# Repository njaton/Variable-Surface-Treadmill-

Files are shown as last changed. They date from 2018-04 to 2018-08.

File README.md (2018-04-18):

# Variable-Surface-Treadmill-

Code Written by Nick Jaton

Project Co-authors Travis Vanderheyden, Dr. Kota Takahashi

This program was created as a proof of concept for the Variable Surface Treadmill Project funded by a NASA Nebraska Space Grant.This program will use three buttons to operate the motors used in the proof of concept. One button is a value generator, one lifts the cell and one resets the cell. The cell movement was operated with a small motor. A TB6612 was used to control the motors.

The Power circuit on the PCB has not yet been tested so please use with caution. The PCB and Schematic are both Eagle files.

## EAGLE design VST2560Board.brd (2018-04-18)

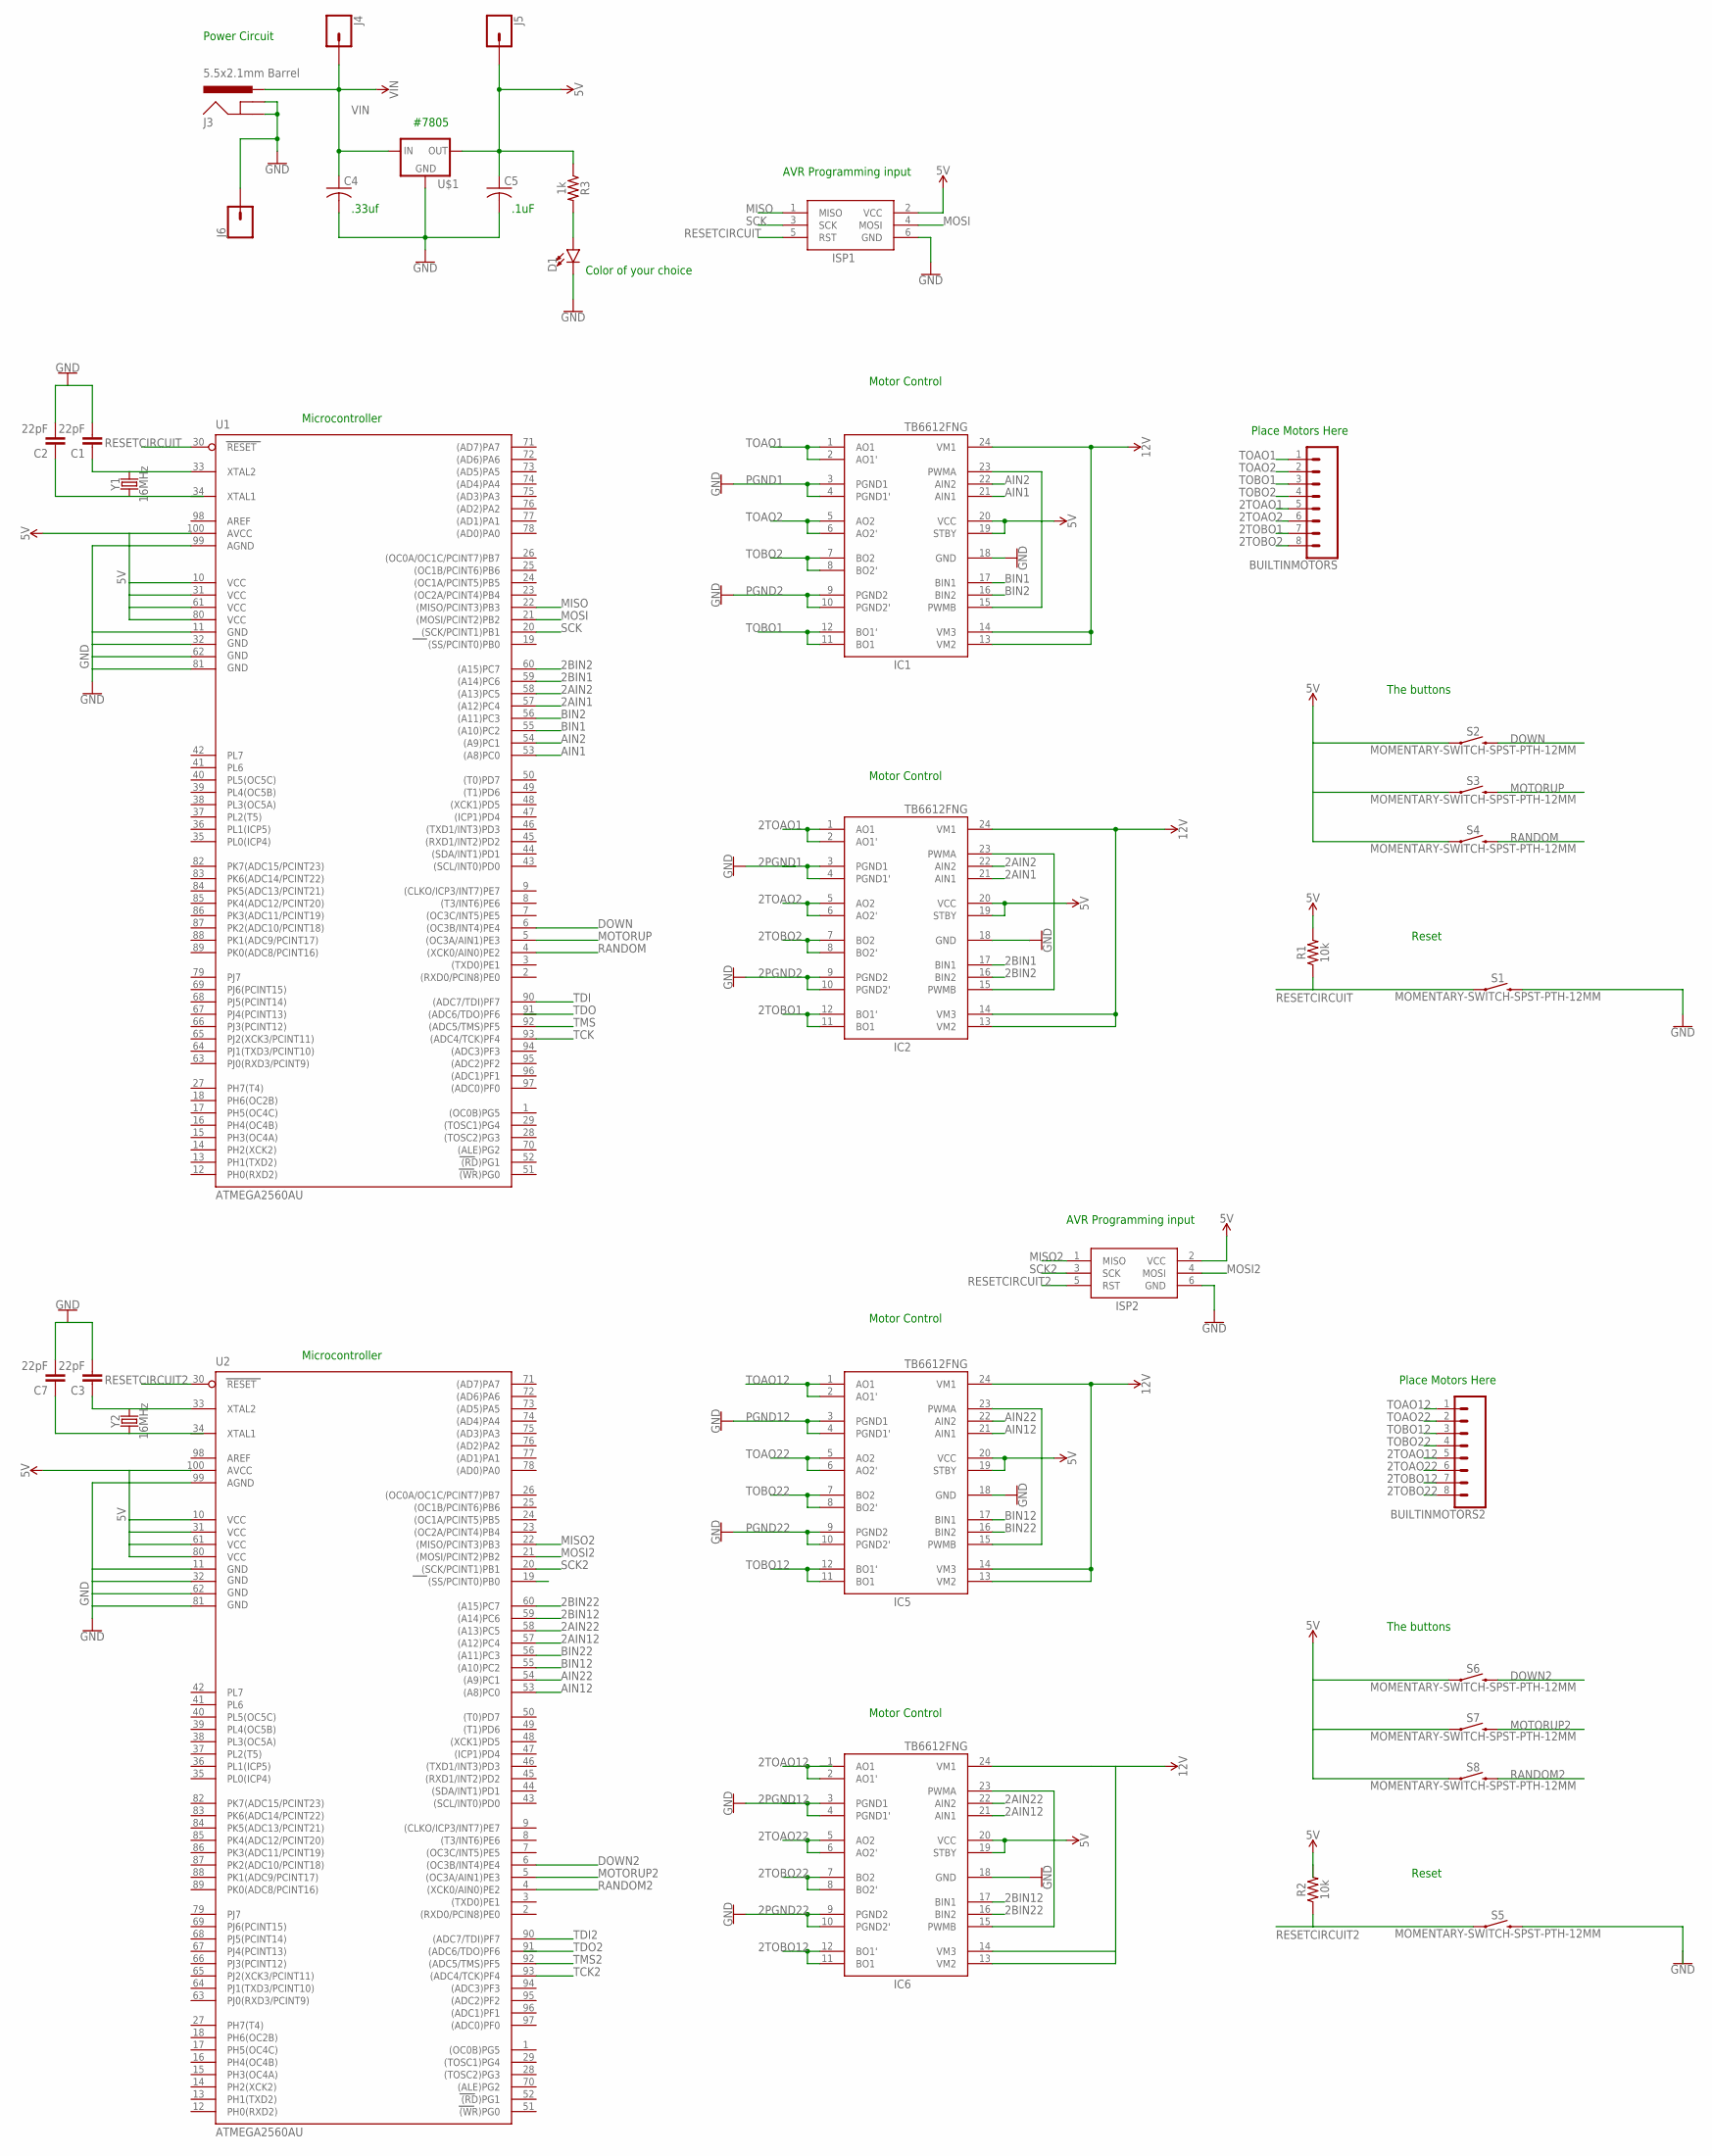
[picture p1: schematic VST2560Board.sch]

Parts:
BUILTINMOTORS, BUILTINMOTORS2: CONN_08"; 1X08
C1, C2, C3, C7: 22pF; 0603
C4, C5: C-USC0603; C0603
D1: LED3MM; LED_3MM
IC1, IC2, IC5, IC6: TB6612FNG; SSOP24
ISP1, ISP2: AVRISP-BOX
J3: 5.5x2.1mm Barrel; POWER_JACK_SMD
J4, J5, J6: CONN_01; 1X01
R1, R2: 10k; AXIAL-0.3
R3: 1k; 0603
S1, S2, S3, S4, S5, S6, S7, S8: MOMENTARY-SWITCH-SPST-PTH-12MM; TACTILE_SWITCH_PTH_12MM
U1, U2: ATMEGA2560AU; TQFP100
U$1: V_REG_LD1117VXX; 78XXL
Y1, Y2: 16MHz; HC49US

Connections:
2AIN1: IC2.21 (AIN1), U1.57 ((A12)PC4)
2AIN2: IC2.22 (AIN2), U1.58 ((A13)PC5)
2AIN12: IC6.21 (AIN1), U2.57 ((A12)PC4)
2AIN22: IC6.22 (AIN2), U2.58 ((A13)PC5)
2BIN1: IC2.17 (BIN1), U1.59 ((A14)PC6)
2BIN2: IC2.16 (BIN2), U1.60 ((A15)PC7)
2BIN12: IC6.17 (BIN1), U2.59 ((A14)PC6)
2BIN22: IC6.16 (BIN2), U2.60 ((A15)PC7)
2PGND1: IC2.3 (PGND1), IC2.4 (PGND1')
2PGND2: IC2.9 (PGND2), IC2.10 (PGND2')
2PGND12: IC6.3 (PGND1), IC6.4 (PGND1')
2PGND22: IC6.9 (PGND2), IC6.10 (PGND2')
2TOAO1: BUILTINMOTORS.5, IC2.1 (AO1), IC2.2 (AO1')
2TOAO2: BUILTINMOTORS.6, IC2.5 (AO2), IC2.6 (AO2')
2TOAO12: BUILTINMOTORS2.5, IC6.1 (AO1), IC6.2 (AO1')
2TOAO22: BUILTINMOTORS2.6, IC6.5 (AO2), IC6.6 (AO2')
2TOBO1: BUILTINMOTORS.7, IC2.11 (BO1), IC2.12 (BO1')
2TOBO2: BUILTINMOTORS.8, IC2.7 (BO2), IC2.8 (BO2')
2TOBO12: BUILTINMOTORS2.7, IC6.11 (BO1), IC6.12 (BO1')
2TOBO22: BUILTINMOTORS2.8, IC6.7 (BO2), IC6.8 (BO2')
5V: C5.1, IC1.15 (PWMB), IC1.19 (STBY), IC1.20 (VCC), IC1.23 (PWMA), IC2.15 (PWMB), IC2.19 (STBY), IC2.20 (VCC), IC2.23 (PWMA), IC5.15 (PWMB), IC5.19 (STBY), IC5.20 (VCC), IC5.23 (PWMA), IC6.15 (PWMB), IC6.19 (STBY), IC6.20 (VCC), IC6.23 (PWMA), ISP1.2 (VCC), ISP2.2 (VCC), J5.1, R1.P$2 (2), R2.P$2 (2), R3.1, S2.1, S3.1, S4.1, S6.1, S7.1, S8.1, U1.10 (VCC), U1.31 (VCC1), U1.61 (VCC2), U1.80 (VCC3), U1.100 (AVCC), U2.10 (VCC), U2.31 (VCC1), U2.61 (VCC2), U2.80 (VCC3), U2.100 (AVCC), U$1.GND (OUT)
12V: IC1.13 (VM2), IC1.14 (VM3), IC1.24 (VM1), IC2.13 (VM2), IC2.14 (VM3), IC2.24 (VM1), IC5.13 (VM2), IC5.14 (VM3), IC5.24 (VM1), IC6.13 (VM2), IC6.24 (VM1)
AIN1: IC1.21 (AIN1), U1.53 ((A8)PC0)
AIN2: IC1.22 (AIN2), U1.54 ((A9)PC1)
AIN12: IC5.21 (AIN1), U2.53 ((A8)PC0)
AIN22: IC5.22 (AIN2), U2.54 ((A9)PC1)
BIN1: IC1.17 (BIN1), U1.55 ((A10)PC2)
BIN2: IC1.16 (BIN2), U1.56 ((A11)PC3)
BIN12: IC5.17 (BIN1), U2.55 ((A10)PC2)
BIN22: IC5.16 (BIN2), U2.56 ((A11)PC3)
DOWN: S2.3 (2), U1.6 ((OC3B/INT4)PE4)
DOWN2: S6.3 (2), U2.6 ((OC3B/INT4)PE4)
GND: C1.2, C2.2, C3.2, C4.2, C5.2, C7.2, D1.K (C), IC1.18 (GND), IC2.18 (GND), IC5.18 (GND), IC6.18 (GND), ISP1.6 (GND), ISP2.6 (GND), J3.GND (GNDBREAK), J3.P$4 (GND), J6.1, S1.3 (2), S5.3 (2), U1.11 (GND), U1.32 (GND1), U1.62 (GND2), U1.81 (GND3), U1.99 (AGND), U2.11 (GND), U2.32 (GND1), U2.62 (GND2), U2.81 (GND3), U2.99 (AGND), U$1.IN (GND)
MISO: ISP1.1 (MISO), U1.22 ((MISO/PCINT3)PB3)
MISO2: ISP2.1 (MISO), U2.22 ((MISO/PCINT3)PB3)
MOSI: ISP1.4 (MOSI), U1.21 ((MOSI/PCINT2)PB2)
MOSI2: ISP2.4 (MOSI), U2.21 ((MOSI/PCINT2)PB2)
MOTORUP: S3.3 (2), U1.5 ((OC3A/AIN1)PE3)
MOTORUP2: S7.3 (2), U2.5 ((OC3A/AIN1)PE3)
unnamed: D1.A, R3.2
unnamed: C2.1, U1.34 (XTAL1), Y1.1
unnamed: C1.1, U1.33 (XTAL2), Y1.2
unnamed: C3.1, U2.33 (XTAL2), Y2.2
unnamed: C7.1, U2.34 (XTAL1), Y2.1
PGND1: IC1.3 (PGND1), IC1.4 (PGND1')
PGND2: IC1.9 (PGND2), IC1.10 (PGND2')
PGND12: IC5.3 (PGND1), IC5.4 (PGND1')
PGND22: IC5.9 (PGND2), IC5.10 (PGND2')
RANDOM: S4.3 (2), U1.4 ((XCK0/AIN0)PE2)
RANDOM2: S8.3 (2), U2.4 ((XCK0/AIN0)PE2)
RESETCIRCUIT: ISP1.5 (RST), R1.P$1 (1), S1.1, U1.30 (RESET)
RESETCIRCUIT2: ISP2.5 (RST), R2.P$1 (1), S5.1, U2.30 (RESET)
SCK: ISP1.3 (SCK), U1.20 ((SCK/PCINT1)PB1)
SCK2: ISP2.3 (SCK), U2.20 ((SCK/PCINT1)PB1)
TCK: U1.93 ((ADC4/TCK)PF4)
TCK2: U2.93 ((ADC4/TCK)PF4)
TDI: U1.90 ((ADC7/TDI)PF7)
TDI2: U2.90 ((ADC7/TDI)PF7)
TMS: U1.92 ((ADC5/TMS)PF5)
TMS2: U2.92 ((ADC5/TMS)PF5)
TOAO1: BUILTINMOTORS.1, IC1.1 (AO1), IC1.2 (AO1')
TOAO2: BUILTINMOTORS.2, IC1.5 (AO2), IC1.6 (AO2')
TOAO12: BUILTINMOTORS2.1, IC5.1 (AO1), IC5.2 (AO1')
TOAO22: BUILTINMOTORS2.2, IC5.5 (AO2), IC5.6 (AO2')
TOBO1: BUILTINMOTORS.3, IC1.11 (BO1), IC1.12 (BO1')
TOBO2: BUILTINMOTORS.4, IC1.7 (BO2), IC1.8 (BO2')
TOBO12: BUILTINMOTORS2.3, IC5.11 (BO1), IC5.12 (BO1')
TOBO22: BUILTINMOTORS2.4, IC5.7 (BO2), IC5.8 (BO2')
VIN: C4.1, J3.VIN0 (PWR), J4.1, U$1.OUT (IN)

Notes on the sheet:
Power Circuit
Microcontroller
Motor Control
The buttons
Reset
AVR Programming input
Place Motors Here
#7805
.1uF
.33uf
Color of your choice

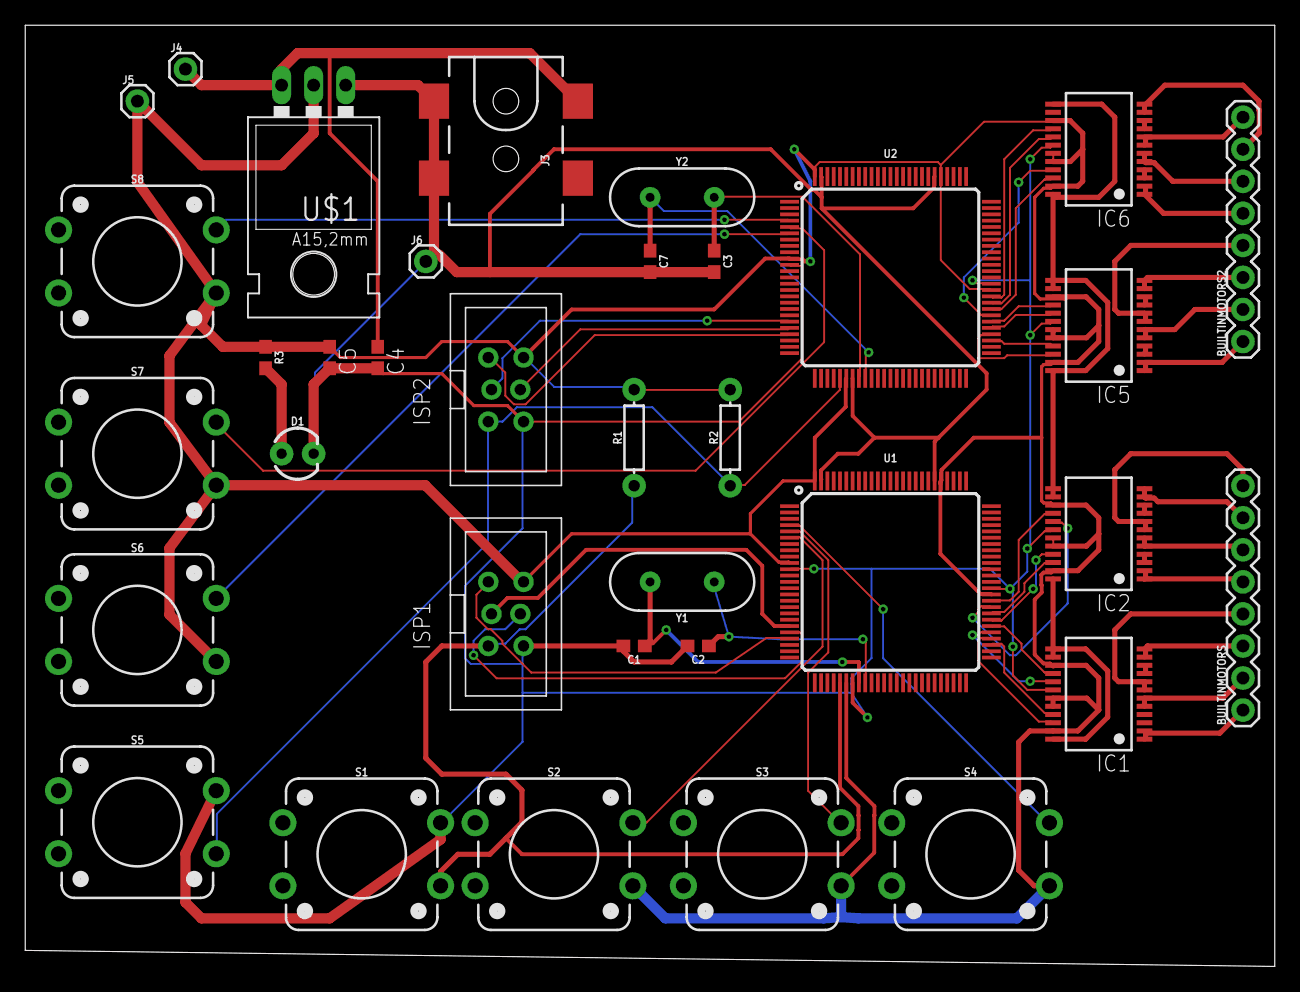
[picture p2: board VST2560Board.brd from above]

Board: 2 copper layers, 99.0 x 74.6 mm, 35 parts (0 on the bottom side), 63 nets.

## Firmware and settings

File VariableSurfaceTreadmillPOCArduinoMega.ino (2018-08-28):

//This program is used to control various motors using the TB6612 motor driver and a atmega 2560. 
//Written by: Nick Jaton
//NASA Nebraska Space Grant
// Property of : University of Nebraska's Biomechanics Research Building

#include <SparkFun_TB6612.h>

//State what pins are used for the TB6612
int MyAIN1[] = {32,40};
int MyAIN2[] = {34,42};
int MyBIN1[] = {30,38};
int MyBIN2[] = {28,36};

int PWMA = 13;
int PWMB = 12;
int PWMC = 11;
int STBY = 10;

const int offsetA = 1;
const int offsetB = -1;
const int offsetC = 1;

int AIN1 = MyAIN1[0];
int AIN2 = MyAIN2[0];

int BIN1 = MyBIN1[0];
int BIN2 = MyBIN2[0];

int AIN3 = MyAIN1[1];
int AIN4 = MyAIN2[1];


// Motor set up 
Motor motor1 = Motor(AIN1, AIN2, PWMA, offsetA, STBY);
Motor motor2 = Motor(BIN1, BIN2, PWMB, offsetB, STBY);
Motor motor3 = Motor(AIN3, AIN4, PWMC, offsetC, STBY);

// Button 1 is used for the random digit generator. 
// Button 2 is used to have the motors move upwards. 
// Button 3 is used to have the motors move back to the home position.
 
const int Button1 = 4;
const int Button2 = 5;
const int Button3 = 7; 

int Button1State = 0;
int Button2State = 0;
int Button3State = 0;

// The different variables that will be used for each motor 
int Rand1 = 0;
int Rand2 = 0;
int Rand3 = 0;


void setup() 
{
  // indicate the Buad number for displaying information
  Serial.begin(9600);
  
  //Set each button as an input 
  pinMode(Button1,INPUT);
  pinMode(Button2,INPUT);
  pinMode(Button3,INPUT); 

}

void loop() 
{  
  // read the information on the buttons 
  Button1State = digitalRead(Button1);
  Button2State = digitalRead(Button2);
  Button3State = digitalRead(Button3);
  
  // Random number generator
  if (Button1State == HIGH) 
  {
    RandomNumbers();
    Button1State = LOW;
    delay(500);
  }
  
  // Move the cell top "upwards"
  if (Button2State == HIGH) 
  {
    MoveUp();
    Button2State = LOW;
    delay(500);
  }
  
  // resets the cell top to the starting position
  if (Button3State == HIGH) 
  {
     MoveDown();
     Button3State = LOW;
     delay(500);
  }
    
}

//Random Number Generator Function
//This will determine the distance for each independent motor.  
void RandomNumbers()
{ 
  Serial.println("Current time values"); //Title
  
  //Motor 1
  Rand1 = random(10000, 20000); 
  Serial.println(Rand1); 
  
  //Motor 2
  Rand2 = random(10000, 20000); 
  Serial.println(Rand2);   
  
  //Motor 3
  Rand3 = random(10000, 20000); 
  Serial.println(Rand3); 
  
  Serial.println("ready for next command");
  
  delay(400);
}

//Upwards Movement Function
//This function will tell the motors to move upwards based on the predetermined value. 
void MoveUp()
{
  delay(100);
  
  //Motor 1
  motor1.drive(255,Rand1); 
  motor1.brake();
  delay(200);
  Serial.print("Motor one moved upwards ");
  Serial.println(Rand1);
  
  //Motor 2
  motor2.drive(255,Rand2); 
  motor2.brake();
  delay(200);
  Serial.print("Motor two moved upwards ");
  Serial.println(Rand2);
  
  //Motor 3
  motor3.drive(255,Rand3); 
  motor3.brake();
  delay(400);
  Serial.print("Motor three moved upwards ");
  Serial.println(Rand3);
}

//Reset Function
//This function works by telling the motors to reverse the same amount that it moved upwards. 
void MoveDown()
{
  delay(100);
  
  //Motor 1
  motor1.drive(-255,Rand1); 
  motor1.brake();
  delay(200);
  Serial.print("Motor one moved downwards ");
  Serial.println(Rand1);
  
  //Motor 2
  motor2.drive(-255,Rand2); 
  motor2.brake();
  delay(200);
  Serial.print("Motor twop moved downwards ");
  Serial.println(Rand2);
  
  //Motor 3
  motor3.drive(-255,Rand3); 
  motor3.brake();
  delay(200);
  Serial.print("Motor three moved downwards ");
  Serial.println(Rand3);
}

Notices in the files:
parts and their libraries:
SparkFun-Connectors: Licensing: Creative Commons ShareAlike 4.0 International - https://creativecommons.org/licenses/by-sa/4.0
